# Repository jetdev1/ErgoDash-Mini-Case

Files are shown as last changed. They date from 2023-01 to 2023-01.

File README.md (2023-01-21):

# -ErgoDash-Mini-Case
This a sandwich-mount case and plate I designed for a handwired ErgoDash Mini. It's my first time doing CAD, feel free to submit PRs or let me know if you've got any suggestions! Also, I would appreciate it if you could attach a link to this page if you print this case and post photos of it.

Some notes about the files:


1. Only use the KMK config files as reference. They're pretty messy as I had to compensate for some errors I made while handwiring.
2. The M3 screw holes are a little tight, so it might take a bit of effort to get in. I used an electric screwdriver, screwed it in all the way and then used reverse mode while pushing it out but... it's easier to just widen the hole.
3. The holes were designed for 3mm x 4.5mm (h x d) heat-set inserts
4. The plate is designed for female header pins 8.5mm tall.
5. The case was designed for use with the Pi Pico.
5. The TRRS cutout is a little narrow and not all cables will fit. Check the diameter of your TRRS cable termination first.
6. The mounting holes above the Pi Pico were originally designed for screwing in either an acrylic cover or a module with an OLED screen, but it is too thin and I don't expect it to hold up well. There isn't much clearance underneat it for an M2 nut either.

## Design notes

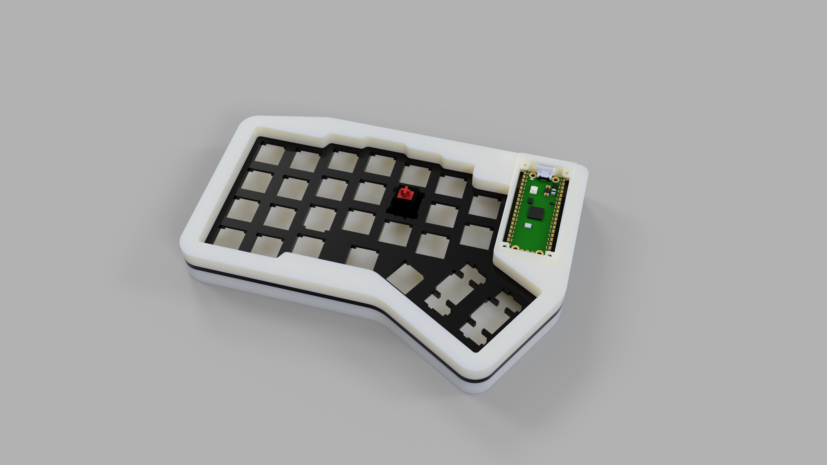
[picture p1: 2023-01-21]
Renders/cb89a9f2-06d8-4f45-bebf-b3c02e5c08be.PNG

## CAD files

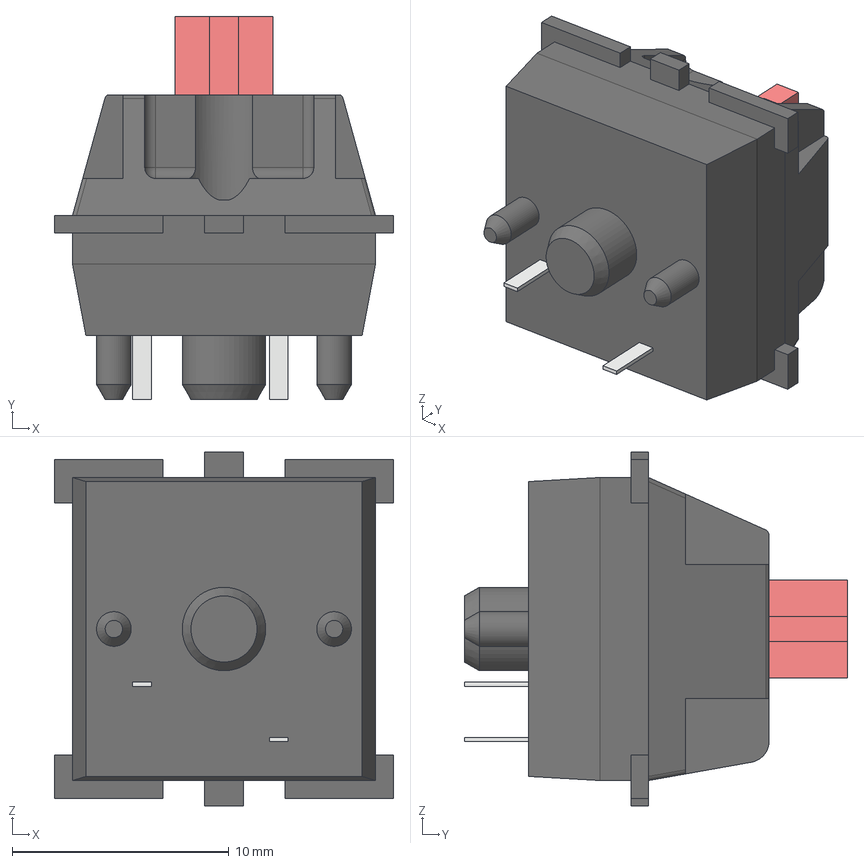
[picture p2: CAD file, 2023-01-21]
Hardware/Electronics/switch.step
15.6 x 17.7 x 16.3 mm

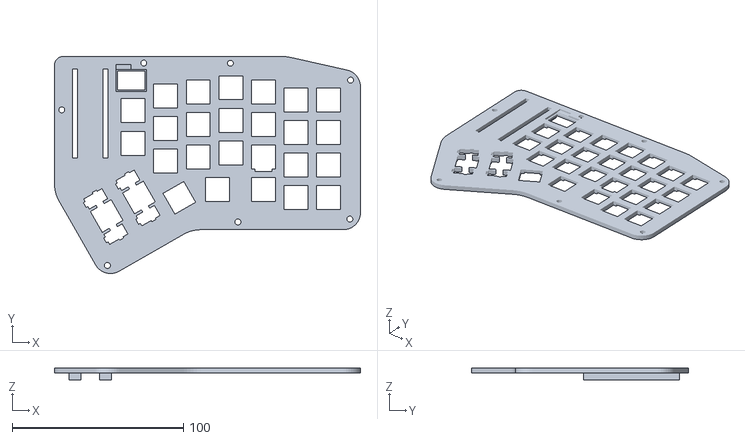
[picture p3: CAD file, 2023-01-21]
Hardware/STL files/KANNSEIIII SHIMASHITA/Plate Mirrored.stl
178.9 x 126.9 x 7.00

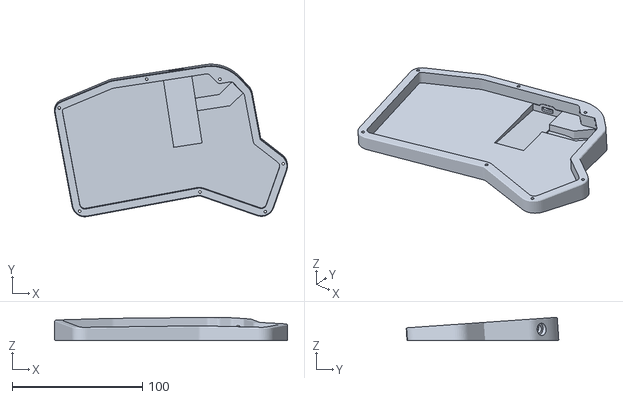
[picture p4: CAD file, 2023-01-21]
Hardware/STL files/Prototype 1/Bottom Case v14.stl
178.6 x 117.0 x 17.9

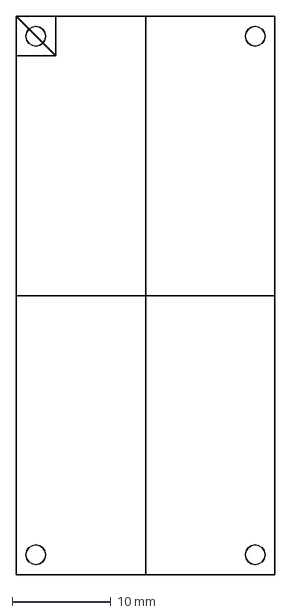
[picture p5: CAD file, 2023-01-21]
Hardware/STL files/KANNSEIIII SHIMASHITA/Acrylic cover.dxf
26.2 x 56.5 mm

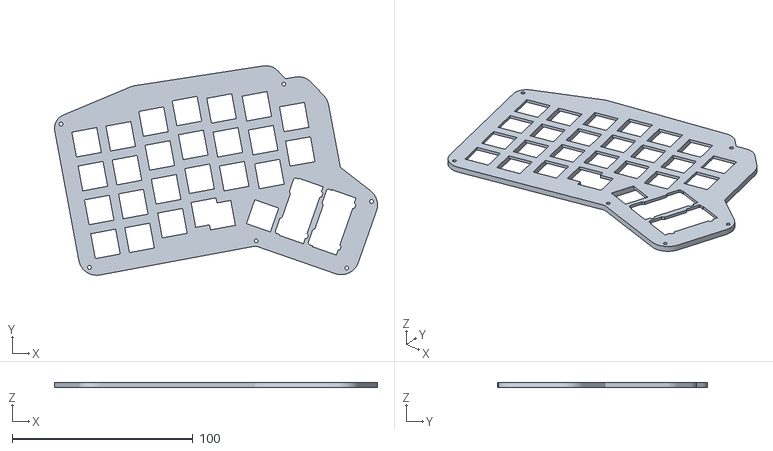
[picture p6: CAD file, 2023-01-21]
Hardware/STL files/Prototype 1/ACtual sWitch PlAte v7.stl
178.6 x 115.9 x 3.00

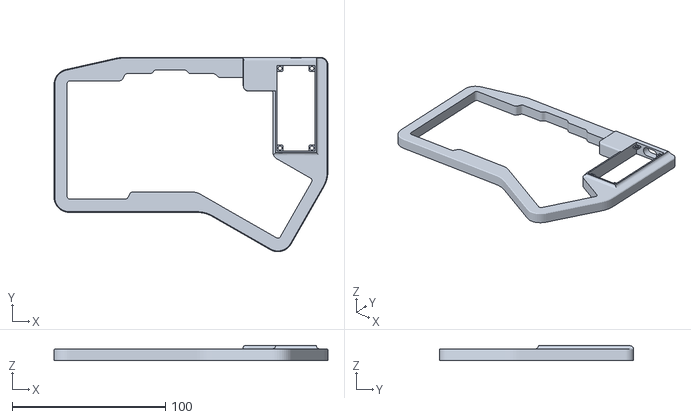
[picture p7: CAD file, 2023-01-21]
Hardware/STL files/KANNSEIIII SHIMASHITA/Top Case.stl
178.9 x 126.9 x 9.50

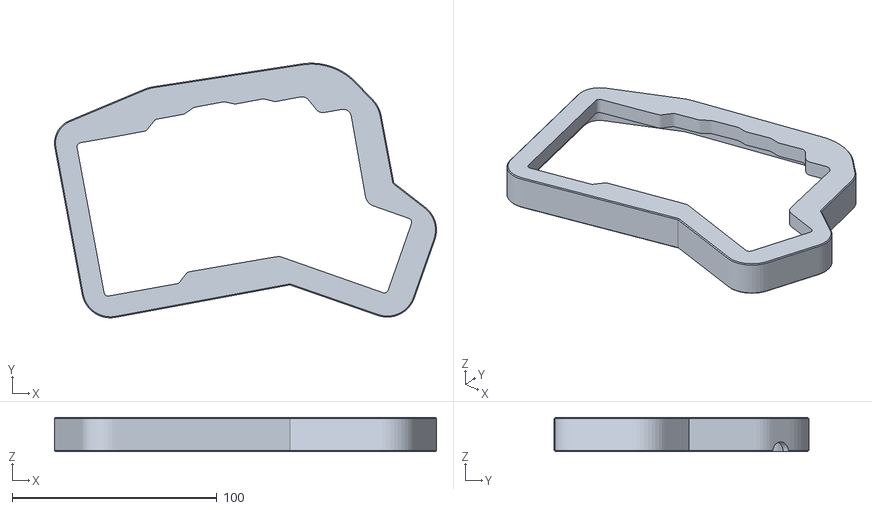
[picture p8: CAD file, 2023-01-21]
Hardware/STL files/Prototype 1/Top Case v13.stl
186.6 x 124.4 x 16.8

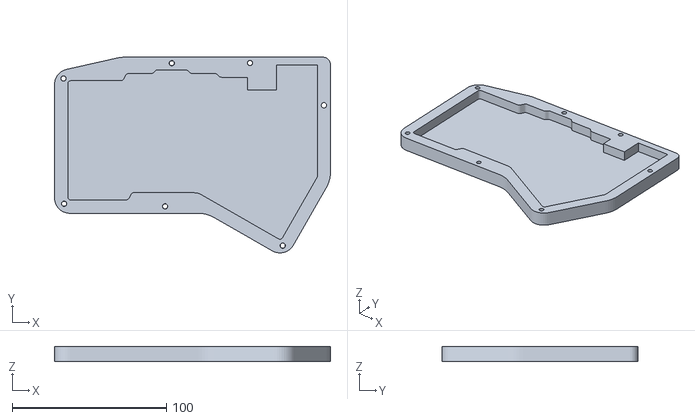
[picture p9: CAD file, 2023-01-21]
Hardware/STL files/KANNSEIIII SHIMASHITA/Bottom Case.stl
178.9 x 126.9 x 10.0

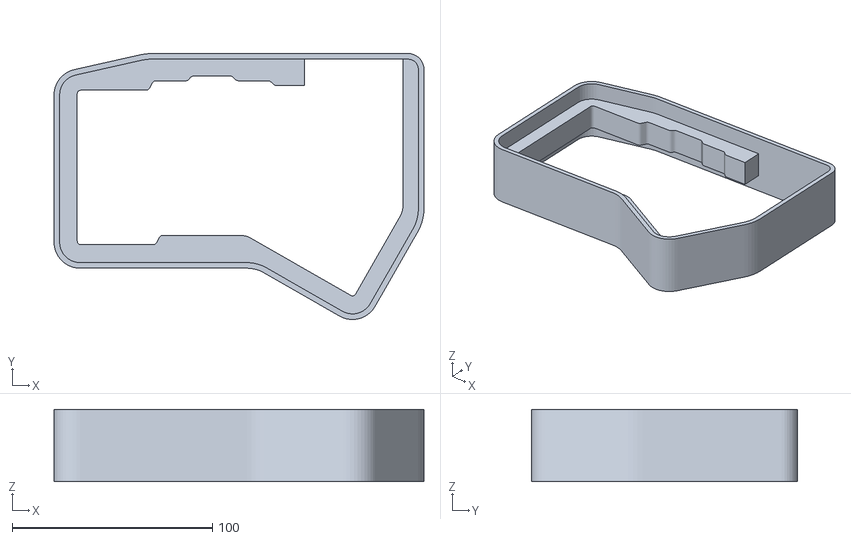
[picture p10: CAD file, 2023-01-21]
Hardware/STL files/KANNSEIIII SHIMASHITA/Travel Case.stl
184.9 x 132.9 x 36.0

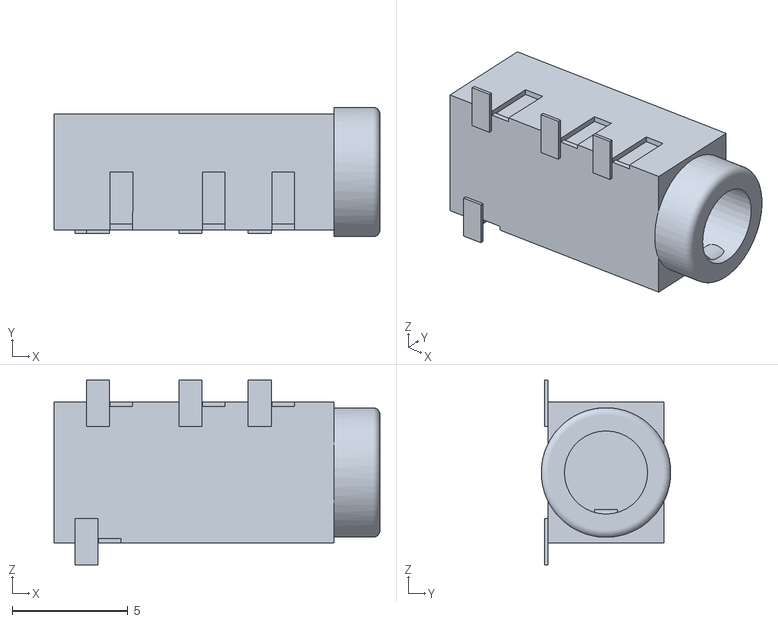
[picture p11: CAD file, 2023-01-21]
Hardware/STL files/12639.STL
14.1 x 5.60 x 8.00

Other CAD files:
Hardware/STL files/KANNSEIIII SHIMASHITA/Bottom Case Mirorred.stl
Hardware/STL files/KANNSEIIII SHIMASHITA/Plate.stl
Hardware/STL files/KANNSEIIII SHIMASHITA/Top Case Mirrored.stl

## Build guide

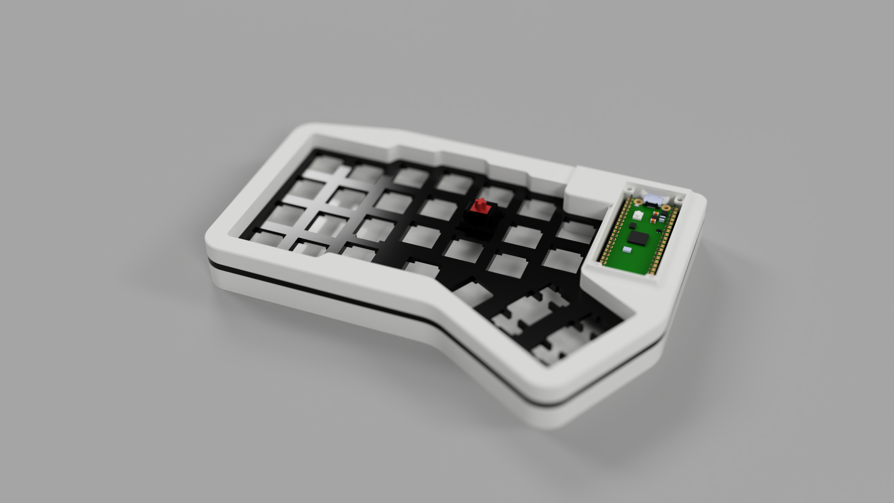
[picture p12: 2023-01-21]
Renders/new_new_assembly_2022-Dec-29_06-24-39AM-000_CustomizedView8820982504_png.png

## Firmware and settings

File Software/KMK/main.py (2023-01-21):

import board
from kb import KMKKeyboard

from kmk.keys import KC
from kmk.extensions.media_keys import MediaKeys

from kmk.modules.layers import Layers
from kmk.modules.modtap import ModTap
from kmk.handlers.sequences import simple_key_sequence

print("Starting")
keyboard = KMKKeyboard()

# Add extensions
keyboard.extensions.append(MediaKeys())
keyboard.modules.append(Layers())
keyboard.modules.append(ModTap())

# Enable debugging
keyboard.debug_enabled = True


# Cleaner Keycodes
# Colemak
XXXXX = KC.NO
SYSLAYER = KC.LT(2, KC.TG(2))
NUMLAYER = KC.LT(1, KC.TG(1))
SSPC = KC.LT(1, KC.SPC)
# Home row mods
MODA = KC.MT(KC.A, KC.LCTL)
MODR = KC.MT(KC.R, KC.LALT)
MODS = KC.MT(KC.S, KC.LGUI)
MODT = KC.MT(KC.T, KC.LSFT)
MODN = KC.MT(KC.N, KC.RSFT)
MODE = KC.MT(KC.E, KC.RGUI)
MODI = KC.MT(KC.I, KC.RALT)
MODO = KC.MT(KC.O, KC.RCTL)

# System
COPYPASTE = KC.MT(KC.LCTL(KC.C), KC.LCTL(KC.V))
tabp = KC.MT(KC.LALT(KC.LGUI, KC.LEFT),KC.LCTL)
tabn = KC.MT(KC.LALT(KC.LGUI, KC.RIGHT), KC.LALT)
deskp = KC.MT(KC.LCTL(KC.LEFT), KC.LGUI)
deskn = KC.MT(KC.LCTL(KC.RIGHT), KC.LSFT)
back = KC.LGUI(KC.LCBR)
fwd = KC.LGUI(KC.RCBR)

layer = []

N = len(keyboard.row_pins) * len(keyboard.col_pins) * 2
for i in range(N):
    c, r = divmod(i, 100)
    d, u = divmod(r, 10)
    layer.append(
        simple_key_sequence(
            (
                getattr(KC, 'N' + str(c)),
                getattr(KC, 'N' + str(d)),
                getattr(KC, 'N' + str(u)),
                KC.SPC,
            )
        )
    )
keyboard.keymap = [layer]

# keyboard.keymap = [
#     [   # COLEMAK DH
#          KC.TAB  ,  KC.Q   ,  KC.W   ,  KC.F  , KC.P  ,  KC.B  , KC.BRIU ,      KC.VOLU  ,   KC.J   ,  KC.L   ,  KC.U   ,  KC.Y   , KC.SCOLON , KC.BSPC ,
#          KC.CAPS ,  KC.A   ,  KC.R   ,  KC.S  , KC.T  ,  KC.G  , KC.BRID ,      KC.VOLD  ,   KC.M   ,  KC.N   ,  KC.E   ,  KC.I   ,   KC.O    , KC.ENT  ,
#          KC.TRNS ,  KC.Z   ,  KC.X   ,  KC.C  , KC.D  ,  KC.V  ,  XXXXX  ,       XXXXX   ,   KC.K   ,  KC.H   , KC.COMM , KC.DOT  ,  KC.SLSH  , KC.QUOT ,
#          KC.TRNS , KC.TRNS , KC.TRNS , KC.ESC , XXXXX , KC.SPC , KC.TRNS ,      SYSLAYER , NUMLAYER , KC.TRNS ,  XXXXX  , KC.MRWD ,  KC.MPLY  , KC.MFFD ,
#     ],
# 
#     [  # NUMBERS AND SYMBOLS
#          KC.TRNS , KC.PSLS , KC.N7   , KC.N8 , KC.N9 , KC.PPLS , KC.TRNS ,    KC.TRNS , KC.BSLS , KC.LCBR , KC.RCBR , KC.DLR  , KC.AT   , KC.CIRC ,
#          KC.TRNS , KC.PAST , KC.N4   , KC.N5 , KC.N6 , KC.PMNS , KC.TRNS ,    KC.TRNS , KC.PIPE , KC.LPRN , KC.RPRN , KC.EXLM , KC.HASH , KC.UNDS ,
#          KC.TRNS , KC.TRNS , KC.N1   , KC.N2 , KC.N3 , KC.DOT  , XXXXX   ,    XXXXX   , KC.TRNS , KC.LBRC , KC.RBRC , KC.AMPR , KC.GRV  , KC.PERC ,
#          KC.TRNS , KC.TRNS , KC.TRNS , KC.N0 , XXXXX , KC.TRNS , KC.TRNS ,    KC.TRNS , KC.TRNS , KC.TRNS , XXXXX   , KC.TRNS , KC.TRNS , KC.TRNS ,
#     ],
# 
#     [  # SYSTEM - macOS
#          KC.TRNS , KC.TRNS , KC.TRNS ,  KC.TRNS   ,  KC.TRNS  , KC.TRNS , KC.TRNS ,     KC.TRNS , KC.TRNS ,  KC.TRNS   , KC.TRNS , KC.TRNS , KC.TRNS , KC.TRNS ,
#          KC.TRNS ,  tabp   ,  tabn   ,  deskp     ,  deskn    , KC.TRNS , KC.TRNS ,     KC.TRNS , KC.LEFT ,  KC.DOWN   , KC.UP   , KC.RGHT , KC.TRNS , KC.TRNS ,
#          KC.TRNS , KC.TRNS , KC.TRNS ,    back    ,  fwd      , KC.TRNS , XXXXX   ,     XXXXX   , KC.TRNS , COPYPASTE  , KC.TRNS , KC.TRNS , KC.TRNS , KC.TRNS ,
#          KC.TRNS , KC.TRNS , KC.TRNS ,  KC.TRNS   ,  XXXXX    , KC.TRNS , KC.TRNS ,     KC.TRNS , KC.TRNS ,  KC.TRNS   , XXXXX   , KC.TRNS , KC.TRNS , KC.TRNS ,
#     ],
# 
#     [  # Fn
#          KC.TRNS , KC.TRNS , KC.F7   , KC.F8   , KC.F9   , KC.F10  , KC.TRNS ,     KC.TRNS , KC.TRNS , KC.TRNS , KC.TRNS , KC.TRNS , KC.TRNS , KC.TRNS ,
#          KC.TRNS , KC.TRNS , KC.F4   , KC.F5   , KC.F6   , KC.F11  , KC.TRNS ,     KC.TRNS , KC.TRNS , KC.TRNS , KC.TRNS , KC.TRNS , KC.TRNS , KC.TRNS ,
#          KC.TRNS , KC.TRNS , KC.F1   , KC.F2   , KC.F3   , KC.F12  , XXXXX   ,     XXXXX   , KC.TRNS , KC.TRNS , KC.TRNS , KC.TRNS , KC.TRNS , KC.TRNS ,
#          KC.TRNS , KC.TRNS , KC.TRNS , KC.TRNS , XXXXX   , KC.TRNS , KC.TRNS ,     KC.TRNS , KC.TRNS , KC.TRNS , XXXXX   , KC.TRNS , KC.TRNS , KC.TRNS ,
#     ],
# 
#     [  # Tetris
#          KC.TRNS , KC.TRNS , KC.TRNS , KC.W    , KC.TRNS , KC.TRNS , KC.TRNS ,     KC.TRNS , KC.TRNS , KC.TRNS , KC.TRNS , KC.TRNS , KC.TRNS , KC.TRNS ,
#          KC.TRNS , KC.TRNS , KC.A    , KC.S    , KC.D    , KC.TRNS , KC.TRNS ,     KC.TRNS , KC.TRNS , KC.J    , KC.TRNS , KC.L    , KC.TRNS , KC.TRNS ,
#          KC.F4   , KC.TRNS , KC.TRNS , KC.TRNS , KC.TRNS , KC.TRNS , XXXXX   ,      XXXXX  , KC.TRNS , KC.TRNS , KC.TRNS , KC.TRNS , KC.TRNS , KC.TRNS ,
#          KC.TRNS , KC.TRNS , KC.TRNS , KC.TRNS , XXXXX   , KC.SPC  , KC.TRNS ,     KC.TRNS , KC.TRNS , KC.TRNS ,  XXXXX  , KC.TRNS , KC.TRNS , KC.TRNS ,
#     ]
# ]
#


if __name__ == '__main__':
    import digitalio
    from time import sleep
    led = digitalio.DigitalInOut(board.LED)
    led.direction = digitalio.Direction.OUTPUT
    led.value = True
    sleep(0.5)
    led.value = False
    
    keyboard.go()

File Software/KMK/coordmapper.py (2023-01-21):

from kmk.handlers.sequences import simple_key_sequence
from kmk.keys import KC

# *2 for split keyboards, which will typically manage twice the number of keys
# of one side. Having this N too large will have no impact (maybe slower boot..)
N = len(keyboard.col_pins) * len(keyboard.row_pins) * 2

keyboard.coord_mapping = list(range(N))

layer = []

for i in range(N):
    c, r = divmod(i, 100)
    d, u = divmod(r, 10)
    layer.append(
        simple_key_sequence(
            (
                getattr(KC, 'N' + str(c)),
                getattr(KC, 'N' + str(d)),
                getattr(KC, 'N' + str(u)),
                KC.SPC,
            )
        )
    )
print(layer)

if __name__ == '__main__':
    keyboard.go()
